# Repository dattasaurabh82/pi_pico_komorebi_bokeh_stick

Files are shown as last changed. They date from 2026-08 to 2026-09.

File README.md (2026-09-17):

# Komorebi (木漏れ日) Bokeh (暈け / ボケ) Stick

An ambient light installation: a Raspberry Pi Pico 2 W with a Pico DVI Sock
feeds a small pico projector, casting slowly breathing komorebi-like light
dapples (sunlight through foliage) onto a wall. Everything is generated
procedurally on the microcontroller: no video files, no computer. With
WiFi it quietly learns what the sky outside is doing and, by default,
gives back what the day withholds (see "A lamp that answers the sky").

Best viewed with the projector slightly defocused: the optical blur turns the
rendered falloffs into true soft penumbra.

## Hardware

- Raspberry Pi Pico 2 W (RP2350 + CYW43439 WiFi). A plain Pico / Pico W
  (RP2040) also runs the renderer; WiFi needs a W board.
- Pico DVI Sock, Luke Wren's CC0 design (the pi3g/buyzero production run;
  the Adafruit DVI Sock is the same pin map): D0 GP12/13, CK GP14/15,
  D2 GP16/17, D1 GP18/19.
- Any HDMI display or projector (signal is DVI 640x480@60, content 320x240)
- One momentary button (GP7 to GND) and a KY-040 rotary encoder
  (GP6/8/9), see below.

### Wiring

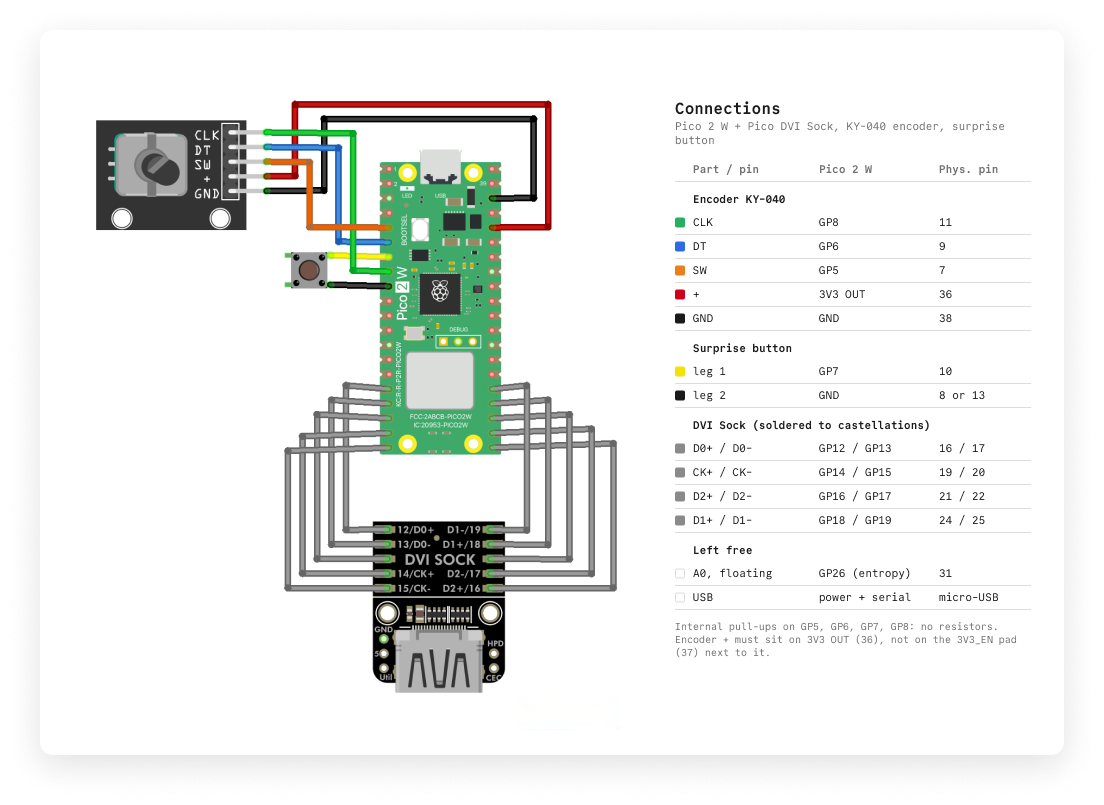
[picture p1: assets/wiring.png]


### Enclosure

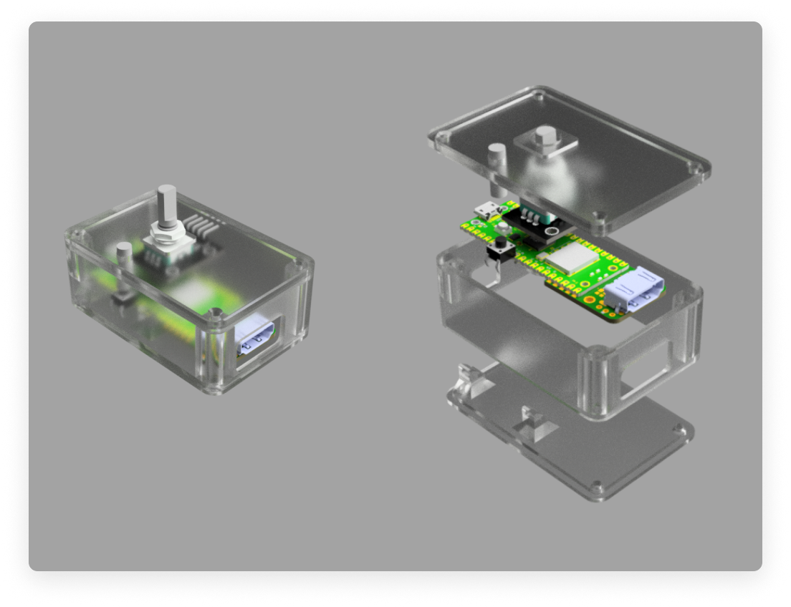
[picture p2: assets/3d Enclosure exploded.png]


>[!Tip]
> The 3D printing enclosure items can be found here: [3D_files/draft](3D_files/draft)

---

## Firmware

### Build and flash

Requires arduino-cli with the Raspberry Pi Pico/RP2040/RP2350 (Earle
Philhower) core, NOT the Mbed core, and the "PicoDVI - Adafruit Fork"
library. Verified with core 6.0.0 and PicoDVI 1.3.2.

```bash
cd main
TMPDIR=/tmp arduino-cli compile --fqbn rp2040:rp2040:rpipico2w \
  -u -p /dev/cu.usbmodem1131201 .
```

`TMPDIR=/tmp` works around a macOS ctags bug in arduino-cli; the port
name may change between replugs (`arduino-cli board list`). The CPU speed
menu does not matter: PicoDVI sets 252 MHz itself. If serial upload hangs
or the board is wedged: hold BOOTSEL while plugging in, then

```bash
TMPDIR=/tmp arduino-cli compile --fqbn rp2040:rp2040:rpipico2w --export-binaries .
cp build/rp2040.rp2040.rpipico2w/main.ino.uf2 /Volumes/RP2350/NEW.UF2
```

Stored WiFi credentials live in the last 4 KB of flash and survive
reflashing.

## How it works

The renderer (in `main/`) is built around one constraint: the second core
is fully occupied generating the DVI signal (PicoDVI bit-bangs TMDS on
PIO, on RP2040 and RP2350 alike), and the renderer was written for a
Cortex-M0+ with no FPU. So everything expensive is precomputed once at
boot into lookup tables, and the per-frame work is integer adds,
multiplies, and shifts.

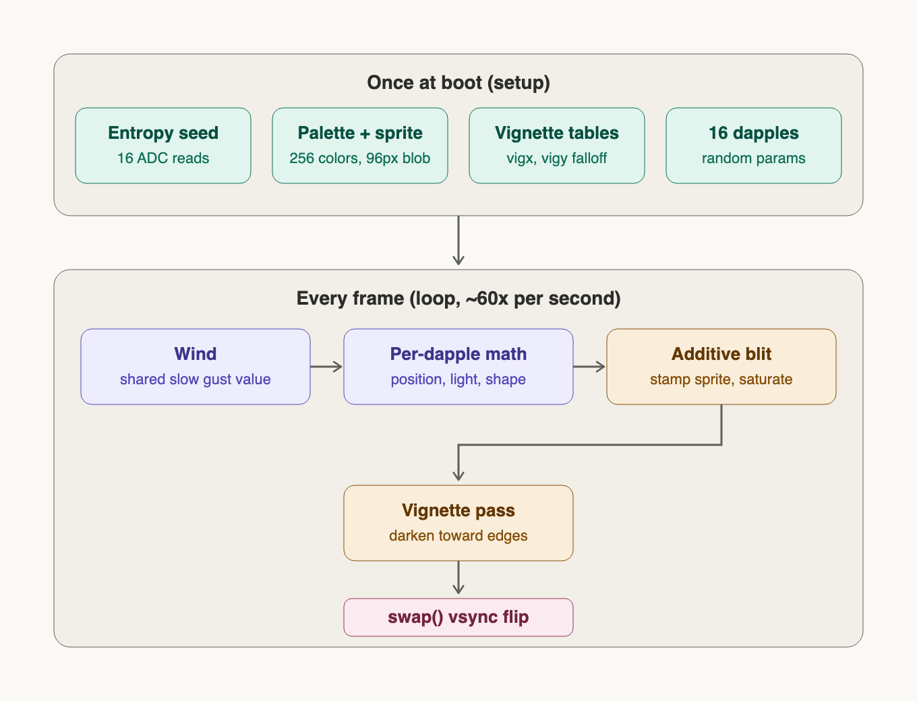
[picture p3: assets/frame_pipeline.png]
Frame pipeline


- **8-bit paletted framebuffer, double-buffered** (`DVIGFX8`, 2 x 77 KB).
  A pixel byte means "amount of light"; a 256-entry pale warm-white palette
  turns that into color. Changing the mood's color = rewriting the palette.
- **Dapples are stamps.** One 96x96 soft radial sprite (smoothstep falloff)
  is precomputed; each of the 16 dapples stamps it scaled to its own
  width/height (ellipticity) and brightness, **additively** with saturation:
  overlapping dapples merge into brighter pools, like real light.
- **Motion is sums of slow sines.** Position = anchor + two small sine
  drifts (periods 100 to 330 s, amplitudes a few px) + a shared "wind" lean.
  Brightness and shape breathe on their own slow sines. Dapples stay
  anchored and breathe; they never travel. Position is a pure function of
  time: nothing accumulates, nothing can drift off.
- **Fresh constellation every power-up.** 16 stirred floating-ADC reads seed
  the RNG; anchors, sizes, periods and phases are re-dealt each boot while
  the overall character stays fixed.
- **Vignette pass** multiplies every pixel by an edge falloff (two 1-D
  tables, `vig = vigx[x] * vigy[y]`), forcing hard black at all four raster
  edges: the wall shows floating light, not a projected rectangle.
- **`swap()`** waits for vsync and flips buffers; no tearing, no half-drawn
  frames.

## The "surprise me" button

One momentary button between **GP7 (physical pin 10) and GND (physical pin
8 or 13)**, two adjacent pins, no resistor needed (internal pull-up).
Enclosure label: *surprise me*.

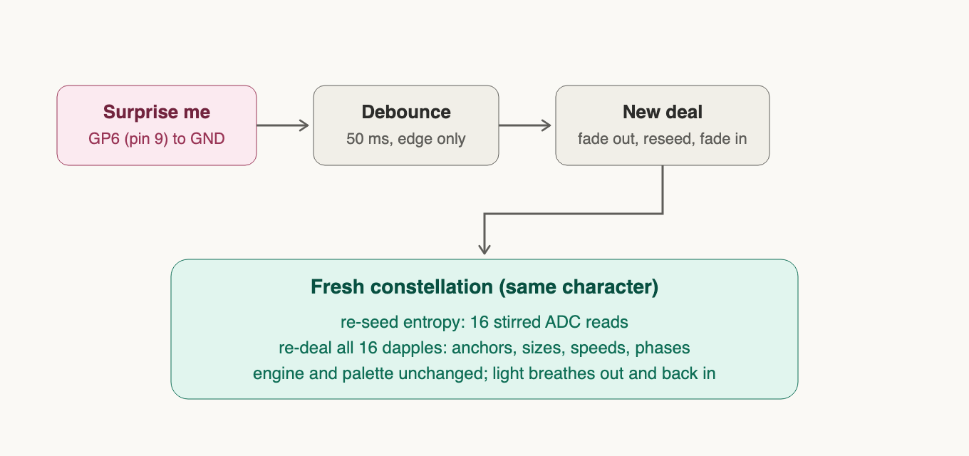
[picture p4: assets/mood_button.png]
Surprise button flow


A press never hard-cuts. The light breathes out (~0.8 s eased fade to
black), the RNG is re-seeded from 16 stirred floating-ADC reads, all 16
dapples are re-dealt (new anchors, sizes, speeds, phases), and the light
breathes back in (~1.2 s). Same character, fresh constellation: the same
thing a power cycle does, minus the wait, plus the grace.

Debounce is 50 ms on the falling edge, and presses are ignored while a
fade is already running.

Mood *presets* (palette temperature + parameter ranges as data) remain an
easy future addition on the same engine.

## The encoder: warmth / breeze / density / contrast

A KY-040 rotary encoder (DT=GP6, CLK=GP8, SW=GP5, physical pins 9/11/7,
GND at pin 38, VCC to **3V3(OUT), never 5V, and not the 3V3_EN pad next
to it**) carries the three adjustable
parameters. Since the piece has no display, the interaction grammar is:

- **Click** cycles the selected parameter: warmth, breeze, density,
  contrast. The selected parameter *announces itself* on the wall in its
  own language. Warmth: a brief palette shimmer. Breeze: a single gust.
  Density: one dapple blinks out and back. Contrast: every pool tightens
  and brightens for a moment.
- **Turn** adjusts the selected parameter, hard-capped to safe ranges
  (warmth, breeze and contrast 0 to 100, density 8 to 28; limits chosen
  by visual spike tests, see `tests/density_spike`). Contrast is the
  "kind of light" dial: at 0 the pools are big, soft and dim like an
  overcast day, at 100 small, bright and hard-edged like full sun.
- After 30 s without interaction, selection falls back to warmth (the
  most lamp-like expectation).
- **Long-press** (0.6 s) forgets the stored WiFi network and reboots into
  the setup portal (next section).

Density changes never re-deal the field: all 28 dapples always exist and
melt in/out of visibility, so turning the knob feels continuous.

The four dials set the baseline. When the piece is online, the sky adds
its own offset on top (next section); the serial log shows both numbers
per detent, "set" and "on the wall".

The encoder is read via **pin-change interrupts** (full quadrature
table), not polling: the render loop runs at 60 Hz (vsync-locked), far
too slow to poll a fast twirl. The four parameters are session-only by design; see the flash rule below.

## WiFi: boot-time setup portal

WiFi exists so the piece can later react to time of day and weather
(not implemented yet). Connecting is solved first, and it is deliberately
plain: no third-party WiFi manager, only the WiFi, WebServer, DNSServer
and EEPROM libraries that ship with the core (`main/wifi_portal.*`,
about 200 lines).

Every boot, before the projector image starts:

1. Read the stored network from EEPROM and try to join it (15 s).
2. Joined: the light starts, online.
3. Not joined, or nothing stored: the board becomes an access point named
   **komorebi** (WPA2 password `komorebi`, both in `config.h`). Join it
   with a phone or laptop; the captive page opens by itself (or open
   http://192.168.4.1). Pick your network from the scanned list, type its
   password (there is a show-password toggle), Save. The board stores it
   and reboots into step 1. A Rescan button drops the AP for a few seconds
   to scan again; rejoin and reload.
4. Nobody configures anything within 3 minutes: the AP goes away and the
   light starts offline. Next power cycle tries again.

To move the piece to another network, long-press the encoder: the board
reboots into step 3. If a Mac is attached, the boot log is on the USB
serial port at 115200 (`[wifi]` lines; the board waits 2 s for a host).

**The flash rule** (why all of this happens before the video starts) is
explained under "Two hard-won facts" below.

## A lamp that answers the sky (in progress)

Once the piece is online it learns, roughly, what the sky is doing
outside: where the sun is, how cloudy or rainy it is, how windy, what
season. It
then uses that knowledge the way a good lamp would, not the way a window
would. On a grey November afternoon it grows brighter, warmer and denser,
like a summer canopy that isn't there. At night it becomes the light the
day withheld. On a sunny June noon it mostly leaves you alone, because
nothing needs compensating. We call this **complement** mode, and it is
the default.

The other mode, **mirror**, does the opposite: the wall shows the sky as
it is. Night is dim and cool, a storm is lively, winter is sparse. Same
model, sign flipped.

Switching between the two is part of the "surprise me" gesture: press
once and the light breathes out and back in with a fresh constellation,
as always. Press twice quickly and it breathes back in as the other
world. The breath is the announcement; there is no other indicator.

What the data changes is deliberately small and slow. Your encoder
settings for warmth, breeze, density and contrast are the intent; the
sky only nudges around them, and every nudge fades in over minutes, so
an hourly update never pops. One constant sets how much the sky is
allowed to nudge at all. Five things are nudged: warmth (sun height,
cooled by cloud), breeze (wind), density (season), brightness (sun and
cloud), contrast (cloud and rain: overcast light is flat, sun is crisp).

Where the knowledge comes from, all free, no accounts, no keys:

- **Open-Meteo** for cloud cover, wind, precipitation, sunrise and sunset,
  and the local time offset. One small request at every boot and sigh.
- **NTP** (the same time servers every computer uses) for the clock.
- **ip-api.com** for a city-level location from the network the piece is
  on, so it still knows where it is after moving house. The sun's height
  and direction are then computed on the board itself, no service needed.

And when it doesn't know? It behaves exactly as it does today. No WiFi,
no data: neutral, both modes identical, the surprise button still works.
Weather fetch failed: the last values are kept for a few hours, then the
piece slowly returns to neutral. Nothing about the sky is ever written
to flash (see the flash rule), so a cold offline boot is simply the
piece you already have.

Status: live on the wall since 14 Sept 2026, in tuning. `SKY_INFLUENCE`
in config.h sets how much the sky may push (1.0 while tuning, 0.3 is
the intended "you'd notice side by side" level). To see it work with a
serial console, follow the step-by-step script in
[tests/README.md](tests/README.md#manual-test-script-for-the-wall-build-main).

## Two hard-won facts about WiFi and video on one Pico

If you build something like this, these two cost us the most time. Both
are handled in the code, and both are worth knowing before you change it.

**1. Flash writes and video do not mix.** Writing the Pico's flash while
the DVI output runs freezes the whole board, even with the video core
stopped first (`tests/eeprom_dvi_spike`, `tests/core1reset_flash_spike`).
So the WiFi portal, and every EEPROM write, runs strictly before
`display.begin()`, and "reconfigure later" is a flag in a watchdog
scratch register plus a reboot, never a live write.

**2. WiFi traffic and video do not mix either.** With DVI live, any
network traffic degrades the station link within minutes (the board
stays "connected" but can't be reached) and, worse, within hours the
video core stops producing frames: the wall goes black and the board
needs a power cycle. Ruled out by experiment: the 252 MHz clock (perfect
without video), power saving, the render code. Left standing: DVI's DMA
and PIO activity against the WiFi chip's SPI DMA. With the radio switched
off after the boot fetch the board ran 16.5 hours without a single
dropped frame; with traffic it died four times in two days.

So the piece does all its networking in the few seconds before the video
starts, and refreshes the sky with a **sigh**: every three hours the
light breathes out, the board reboots with your dials and mode preserved
in watchdog scratch registers, joins WiFi, fetches, and breathes back in.
About ten seconds of dark, three times a day. Sun position and season
stay live from the clock in between; only the weather ages, and it is
kept for six hours before fading toward neutral.

The reboot also resets the video output, so a monitor that lost sync
during the dark gap re-syncs by itself (tested).

How this was found: `tests/sky_spike` with a `SPIKE_MODE` switch (no
video / no video at 252 MHz / video live), a Mac-side log pinging the
router and the weather API in parallel, a hardware watchdog with a
"last stage" recorder in a scratch register, an overnight bisect with the
radio off, and `tests/flash.sh` for reliable flashing on macOS. The
live-traffic code path (keepalive, hourly fetch, reconnects) is still in
`sky.cpp` behind `SKY_LIVE_NET`, off.

## Code layout (main/)

```
main.ino        thin orchestrator: wifi.boot() → display → inputs → engine → swap
config.h        every pin, limit, tuning constant, WiFi name/timeouts
engine.*        KomorebiEngine: dapples, palette, fades, announcements
render.*        fx:: sprite/vignette tables, additive scaled blit
controls.*      RotaryEncoder (ISR quadrature) + ClickButton grammar
params.h        the three user values + capped adjustment
wifi_portal.*   boot-time connect / captive portal / forget-and-reboot
sky_core.*      pure sky maths: JSON scan, sun position, model, decay (host-tested)
sky.*           SkyClient: fetches, clock, keepalive, reconnects, staleness
```

## Repo layout

```
main/            current installation sketch (build this)
komorebi/        variant A, first anchored-dapple baseline (frozen)
komorebi_noise/  variant C, morphing noise-field style (frozen reference)
tests/           proven experiments, setup notes, troubleshooting, fallback plans
assets/          diagrams (SVG sources + rendered PNGs)
```

Variant history and comparisons: see commit log. A/C are kept diffable
against `main/` on purpose.

---

## LICENSE

[MIT](LICENSE)

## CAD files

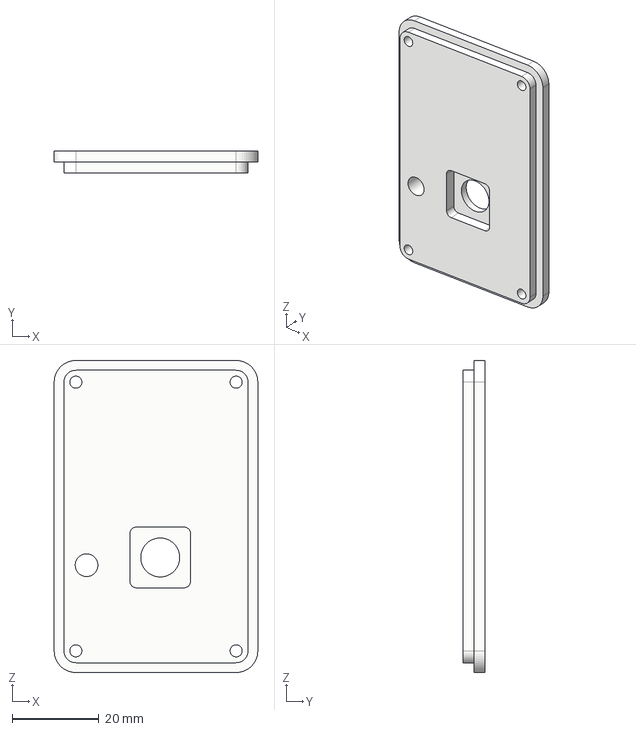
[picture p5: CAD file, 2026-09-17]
3D_files/draft/CAP.step
47.0 x 5.00 x 72.0 mm

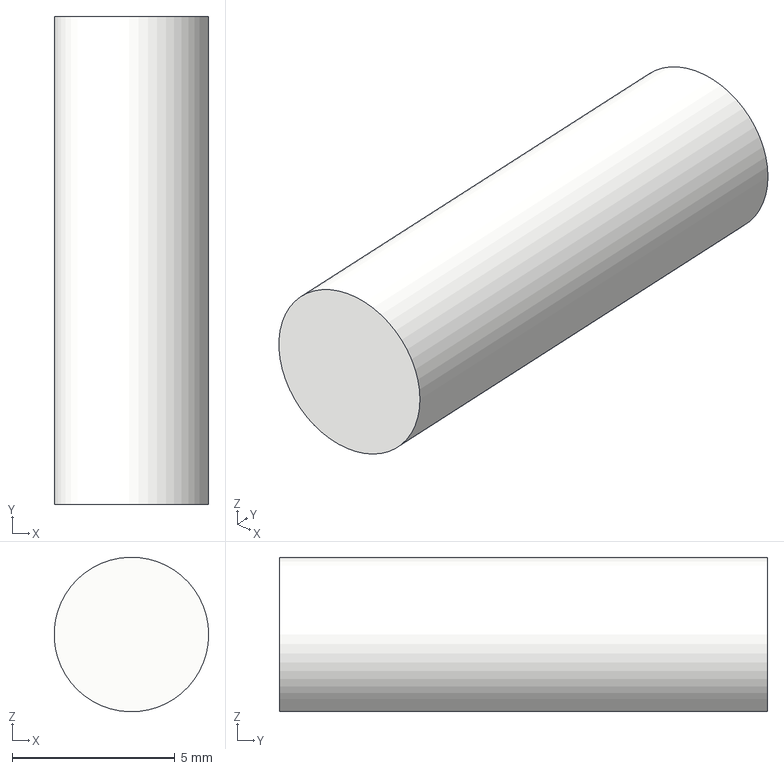
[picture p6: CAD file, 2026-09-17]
3D_files/draft/BTN_EXTENDER.step
4.75 x 15.0 x 4.75 mm

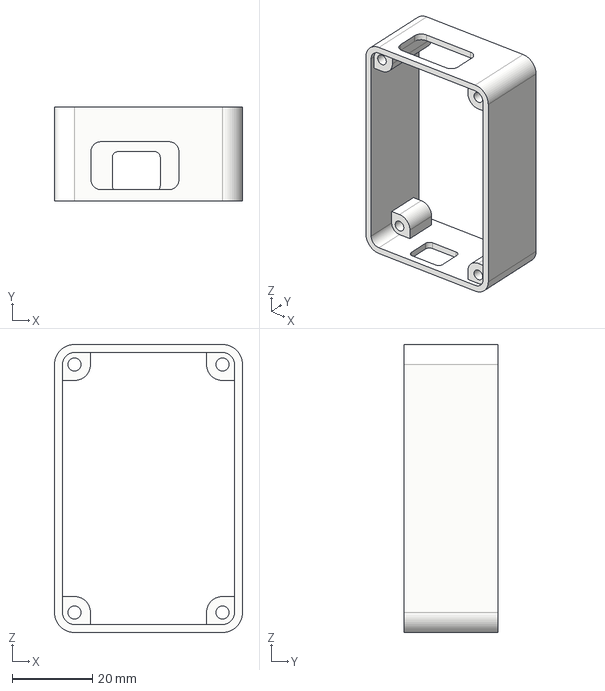
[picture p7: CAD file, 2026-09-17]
3D_files/draft/WALL.step
47.0 x 23.5 x 72.0 mm

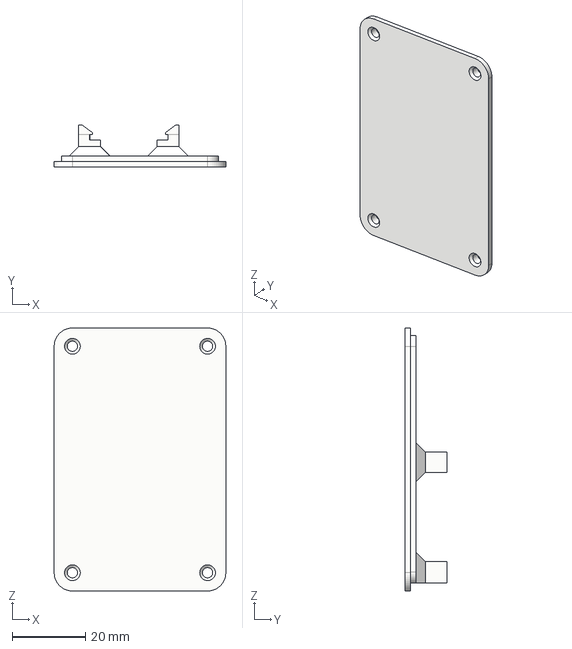
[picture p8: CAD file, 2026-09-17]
3D_files/draft/BASE.step
47.0 x 11.4 x 72.0 mm

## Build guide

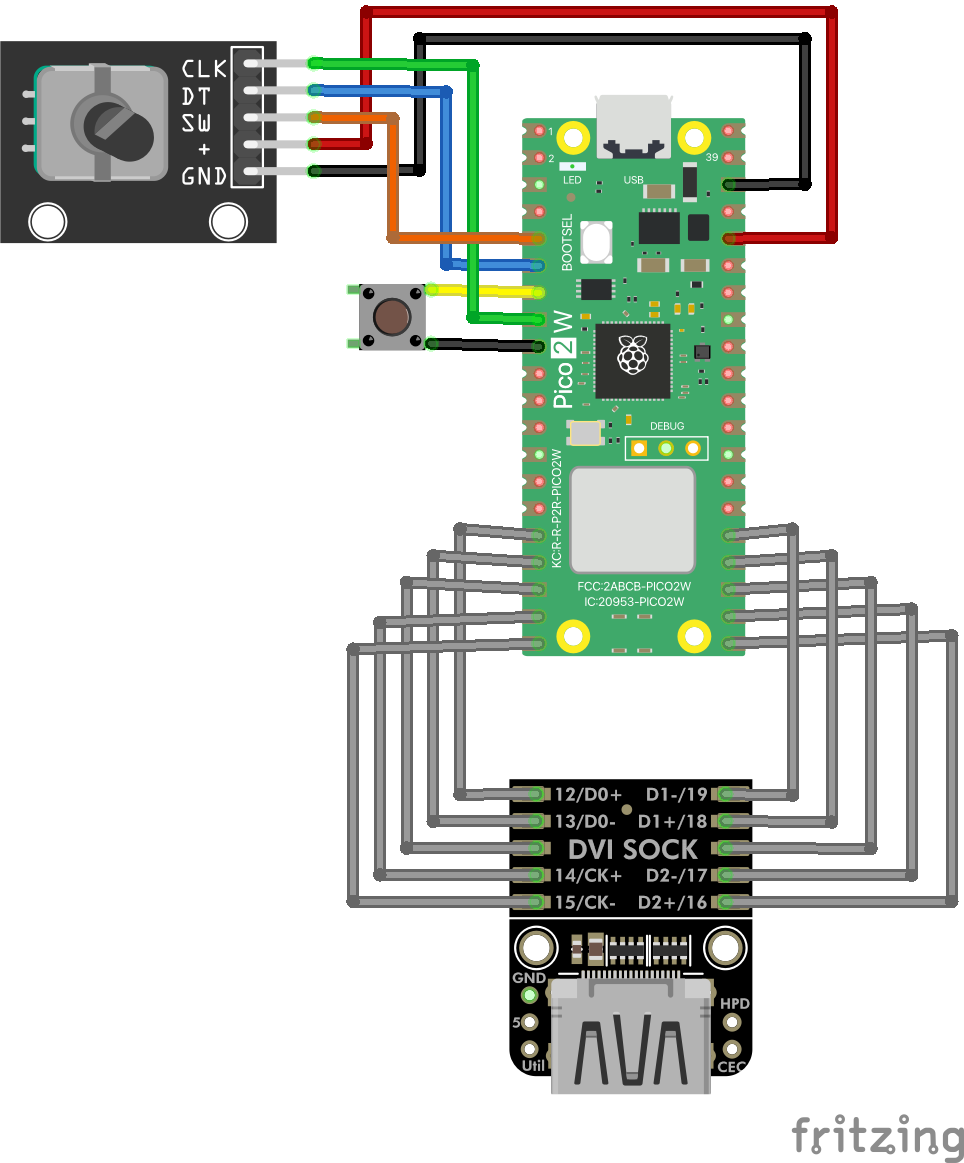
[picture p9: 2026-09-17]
assets/wiring_bb.png

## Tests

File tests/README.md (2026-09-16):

# pi_pico_komorebi: DVI and WiFi setup notes

Hardware: Raspberry Pi Pico 2 W (RP2350; a plain Pico RP2040 also works for
video) + Pico DVI Sock (Luke Wren design, pi3g/buyzero or Adafruit), HDMI out.
Toolchain: Arduino IDE / arduino-cli with the **Raspberry Pi Pico/RP2040/RP2350
(Earle Philhower) core**, the Mbed RP2040 core does NOT work with PicoDVI.
Library: PicoDVI - Adafruit Fork (1.3.2), which on RP2350 still bit-bangs
TMDS on PIO with core1 (no HSTX).

## The one code change that made video work

The `16bit_hello` example ships configured for the **Adafruit Feather RP2040
DVI**, which routes TMDS on different GPIOs. On a plain Pico with the DVI
Sock, that line must use the Sock's pin map:

```cpp
// before (example default): video goes to pins the Sock isn't on, black screen
DVIGFX16 display(DVI_RES_320x240p60, adafruit_feather_dvi_cfg);

// after: matches the DVI Sock (D0 GP12/13, CK GP14/15, D2 GP16/17, D1 GP18/19)
DVIGFX16 display(DVI_RES_320x240p60, pico_sock_cfg);
```

## Board / build settings

- Board: Raspberry Pi Pico 2 W, `rp2040:rp2040:rpipico2w` (plain Pico:
  `rp2040:rp2040:rpipico`)
- CPU speed menu: irrelevant. DVI 640x480 needs a 252 MHz TMDS bit clock and
  the library sets it inside `display.begin()` via `set_sys_clock_khz()`.
- Upload method: default (UF2). BOOTSEL volume is named `RPI-RP2` on RP2040
  and `RP2350` on RP2350.

## Spikes in this folder

- `hello_world` the first working video, DVIGFX16
- `dvigfx8_test` paletted double-buffered canvas, chosen for the piece
- `density_spike` how many dapples before additive blowout (8 to 28)
- `eeprom_dvi_spike` EEPROM.commit() with DVI live on RP2040: video core dies
- `wifi_dvi_spike` (Pico 2 W) scan + softAP + WebServer with DVI live at
  252 MHz sysclk: PASS, the fixed CYW43 PIO clock divider is fine
- `core1reset_flash_spike` (Pico 2 W) EEPROM.commit() with DVI live after
  stopping core1 (v1 `multicore_reset_core1`, v2 PSM hold): the whole board
  freezes inside the commit, USB dead. Recovery: BOOTSEL replug. This is why
  every flash write in `main/` happens before `display.begin()`.
- `sky_host` host-side tests for `main/sky_core` (`./run.sh`, clang, no
  hardware): 54 checks against real Open-Meteo / ip-api responses, broken
  inputs, sun position vs sunrise/sunset and solstices.
- `sky_spike` (Pico 2 W) the real `main/sky.*` via symlinks, DVI live,
  frame-stall meter, serial commands for failure injection, `SPIKE_MODE`
  switch (0 no DVI, 1 no DVI at 252 MHz, 2 DVI live). Found that DVI
  activity degrades the STA link and that a 15 s UDP keepalive holds it.
  See the main README, "Two hard-won facts".
- `flash.sh <sketch_dir>` compile + 1200-baud reset + wait for the RP2350
  volume + copy. Use this; arduino-cli's own upload scan gives up before
  the volume mounts on macOS.

## Failure signals

- Solid video: all good.
- Onboard LED blinking ~1 Hz: `display.begin()` failed (RAM / config).
- Dead LED + black screen: wiring / solder joints on Sock pins GP12 to GP19.
- Dark screen for up to 3 min after boot with a "komorebi" WiFi network
  visible: the setup portal is waiting (see main README).
- USB port present but every open blocks: board frozen by a flash write
  with DVI live. BOOTSEL replug.

## macOS quirks

- **arduino-cli builds fail with "exit status 1"** and a buried `ctags: cannot
  open temporary file`: the bundled ctags 5.8 chokes on macOS's per-user
  TMPDIR. Fix: prefix builds with `TMPDIR=/tmp`:

  ```bash
  TMPDIR=/tmp arduino-cli compile --fqbn rp2040:rp2040:rpipico2w --export-binaries hello_world
  ```

- **Serial upload is flaky**: the 1200-baud touch that reboots the Pico into
  BOOTSEL doesn't always enumerate cleanly on macOS. If it hangs at "Waiting
  for upload port", hold BOOTSEL while plugging in and copy the built UF2 onto
  the `RP2350` (or `RPI-RP2`) volume as `NEW.UF2`.
- **Reading the boot log**: `cat /dev/cu.usbmodem*` can block forever on a
  wedged board. A non-blocking open/read loop (python `os.open` with
  `O_NONBLOCK`) is safer; the main sketch waits 2 s for a host so the first
  lines are not lost.

## Manual test script for the wall build (main/)

Open the serial port at 115200 (the board waits 2 s for a host at boot),
`LOG_VERBOSE 1` in config.h. Each step: what to do, what the wall does,
what the log says.

1. **Boot with the Mac attached.** Replug the board. Within ~3 s: the
   `[wifi] connected` line, three fetch lines (location, ntp, weather),
   the `[sky] ---- snapshot ----` block (time, place, sun, weather, model,
   mode, targets), then `[sky] targets (boot): ...`. Over the next 3 min
   the light slides from the encoder baseline to the sky targets; the
   `[sky] applied: ... -> wall ...` line every minute shows the creep.
2. **Surprise, single click.** Wall: breathe out, new constellation,
   breathe in. Log: `[btn] surprise: breathe out, re-deal, breathe in`.
   A click during the fade logs `ignored (fade running)`.
3. **Double-click** (second press within 350 ms). The first press still
   breathes. Log: `[btn] double-click: mode -> mirror` and a fresh snapshot
   whose targets have flipped sign (warmth +10 becomes -10, contrast +14
   becomes -14, etc.). The
   wall does not jump: the offsets slide over 3 min, so only the direction
   of drift changes. Double-click again flips back to complement.
4. **Encoder click.** Log: `[enc] click: selected breeze (announcing)`,
   wall: one gust. Density: one pool blinks. Warmth: a palette shimmer.
   Contrast: all pools tighten and brighten for a moment. Four clicks
   bring you back to warmth.
5. **Encoder turn.** Per detent: `[enc] turn +1: warmth set 54 (on the
   wall 64 incl. sky)`. "set" is the encoder value, "on the wall" adds the
   sky offset: what the palette is actually built from.
6. **Idle 30 s** with breeze or density selected: `[enc] idle 30 s:
   selection back to warmth`.
7. **Long-press the encoder** (0.6 s): `[enc] long-press: forget WiFi,
   reboot into portal`, then the portal as in the README.
8. **The sigh.** After `SKY_SIGH_MINUTES` (set it to 3 for a test):
   `[sigh] N min up: breathing out, will reboot to refresh the sky`, the
   port drops for a second, then `[boot] sigh reboot: dials restored
   (...)`, the three fetch lines, a snapshot, `radio off`. Dials, mode
   and the picture must all be back.
9. **Watchdog.** If the loop ever stalls 8 s the board reboots itself and
   the boot line says `WATCHDOG REBOOT ... last stage N` (stages listed in
   `log.h`). Seeing this line is a bug report; save the log.

Knobs while testing (config.h): `SKY_INFLUENCE` (1.0 = full swing for
tuning, 0.3 = subtle), `SKY_RANGE_*` per parameter, `SKY_SLEW_S` (180;
set 20 to watch the slide), `LOG_VERBOSE` (0 = boot, fetches, mode
flips, long-press, errors only). The look of "flat" vs "crisp" lives in
`engine.cpp` (`sizeM`, `briM`, the palette gamma multiplier).

Reading the model line: `light warmth motion foliage crisp`, each 0..1
with 0.5 = an average day. Complement pushes every offset away from the
value, mirror toward it; a 0.5 gives a zero offset in both modes.

## The "sigh": implemented (16 Sept 2026)

Status: this is the shipped design, not a fallback. The keepalive approach
was tried and lost the bisect (see the main README, "Two hard-won facts").
Interval `SKY_SIGH_MINUTES` in config.h (180). Tested 4 of 4 cycles at a
3-minute interval with the user watching: dials and mode restored, fresh
fetch each time, monitor re-synced after every dark gap.

### The problem it sidesteps

Two things this board cannot do reliably while the DVI output is running:
write flash, and keep a WiFi station link healthy over hours. Both work
fine before `display.begin()`. So instead of fighting for a live link,
the piece can do all its networking in the few seconds before the video
starts, and simply start over once an hour.

### What it looks like on the wall

Every three hours (interval in `config.h`), the light breathes out over
about a second, the wall is dark for about ten seconds (boot, WiFi join,
three fetches), and the light breathes back in with a fresh constellation. The same gesture as the
"surprise me" button, on a slow clock. On a piece that changes over
minutes, one absence per hour is part of the character, not a glitch.

### What happens underneath

1. The engine fades to black (the existing surprise fade-out).
2. Warmth, breeze, density, contrast and the complement/mirror mode are
   written to watchdog scratch registers 1 and 2. These survive
   `rp2040.reboot()` and touch no flash. Register 0 is the portal flag,
   register 3 the stage recorder.
3. `rp2040.reboot()`.
4. Boot as today: WiFi joins the stored network, the sky layer fetches
   location, clock and weather (about 1.5 s, all before the video),
   the scratch registers restore the parameters, the video starts, the
   light fades in.

Nothing about the sky needs to persist: the model is rebuilt from the
boot fetch. If WiFi is down at that boot, the piece runs neutral until
the next sigh, exactly like an offline boot today.

### What it costs

- 3 to 5 seconds of darkness per interval.
- A new constellation each time (could be kept by also saving the RNG
  seed to a scratch register, if continuity matters more than freshness).
- Nothing else: no keepalive, no reconnect logic, no live fetch code path
  needs to be exercised at all.

### Why it is the default

Live traffic under video killed the video core four times in two days;
the radio-off run went 16.5 hours without a dropped frame. Ten seconds of
dark three times a day is the price of a board that never needs a plug
pulled.

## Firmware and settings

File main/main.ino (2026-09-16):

// pi_pico_komorebi — main.ino: thin orchestrator only.
// All tuning lives in config.h; behavior in engine/render/controls/params.
//
// Hardware: Pico 2 W + Pico DVI Sock (pico_sock_cfg, GP12-19).
//   GP7 (pin 10): "surprise me" button, to GND (pin 8 or 13).
//   GP6/8/5 (pins 9/11/7): KY-040 encoder DT/CLK/SW, GND at pin 38, VCC 3V3.
// WiFi: on boot, join the stored network or open the "komorebi" AP portal
//   (wifi_portal.h). Everything WiFi that writes flash happens BEFORE
//   display.begin(): a flash write with DVI live freezes the board.
// Interaction: encoder click cycles warmth -> breeze -> density -> contrast (the
// selected parameter announces itself visually); turning adjusts it.
// Selection falls back to warmth after SELECT_TIMEOUT_MS of inactivity.
// Encoder long-press: forget the WiFi network, reboot into the portal.

#include <PicoDVI.h>
#include "config.h"
#include "params.h"
#include "controls.h"
#include "engine.h"
#include "wifi_portal.h"
#include "sky.h"
#include "log.h"

// Subclass only to read the video core's late-scanline counter (protected).
struct DVIGFX8Probe : public DVIGFX8 {
  using DVIGFX8::DVIGFX8;
  unsigned lateScanlines() const { return dvi0.late_scanline_ctr; }
};
DVIGFX8Probe display(DVI_RES_320x240p60, true, pico_sock_cfg);

KomorebiEngine engine;
RotaryEncoder  encoder;
ClickButton    encoderBtn;
ClickButton    surpriseBtn;
Params         params;
WifiPortal     wifi;
SkyClient      skyc;       // sky data layer
bool           skyComplement = SKY_DEFAULT_COMPLEMENT;   // false = mirror
uint32_t       lastSurpriseClick = 0;

Param    selected = Param::Warmth;
uint32_t lastInteraction = 0;

// Dials and mode survive a sigh reboot in watchdog scratch registers
// ([0] portal flag, [3] stage recorder; [1] dials, [2] magic + mode).
static constexpr uint32_t SIGH_MAGIC = 0x53494700;   // "SIG" + mode bit
static void saveStateForReboot() {
  watchdog_hw->scratch[1] = ((uint32_t)params.warmth << 24) | ((uint32_t)params.breeze << 16) |
                            ((uint32_t)params.density << 8) | (uint32_t)params.contrast;
  watchdog_hw->scratch[2] = SIGH_MAGIC | (skyComplement ? 1 : 0);
}
static bool restoreStateAfterReboot() {
  if ((watchdog_hw->scratch[2] & 0xFFFFFF00) != SIGH_MAGIC) return false;
  uint32_t d = watchdog_hw->scratch[1];
  params.warmth = (d >> 24) & 0xFF; params.breeze = (d >> 16) & 0xFF;
  params.density = (d >> 8) & 0xFF; params.contrast = d & 0xFF;
  skyComplement = watchdog_hw->scratch[2] & 1;
  watchdog_hw->scratch[2] = 0;
  return true;
}

static const char* modeName() { return skyComplement ? "complement" : "mirror"; }
static sky::Offsets skyOffsets() {
  sky::OffsetRanges r = { SKY_RANGE_WARMTH, SKY_RANGE_BREEZE, SKY_RANGE_DENSITY, SKY_RANGE_EXPOSURE, SKY_RANGE_CONTRAST };
  return sky::mapOffsets(skyc.vector(), skyComplement ? -1 : +1, SKY_INFLUENCE, r);
}
static void pushSky(const char* why) {        // recompute targets, hand to engine, say so
  STAGE(11);
  sky::Offsets o = skyOffsets();
  engine.setSkyTargets(o);
  LOGV("[sky] targets (%s): warmth %+.0f breeze %+.0f density %+.1f exposure %+.0f%% contrast %+.0f\n",
       why, o.warmth, o.breeze, o.density, o.exposure * 100.0f, o.contrast);
}

void setup() {
  SkyClient::prepareRadioForDvi();  // first: WiFi SPI divisor for the 252 MHz DVI clock
  bool wdReboot = watchdog_caused_reboot();
  uint32_t lastStage = watchdog_hw->scratch[3];
  STAGE(0);
  wifi.boot(); // connect, or portal, or time out. MUST precede display.begin().
  bool sighReboot = restoreStateAfterReboot();
  if (sighReboot)   LOGE("[boot] sigh reboot: dials restored (warmth %d breeze %d density %d contrast %d, %s)\n",
                         params.warmth, params.breeze, params.density, params.contrast, modeName());
  else if (wdReboot) LOGE("[boot] WATCHDOG REBOOT: the loop stalled >8 s, last stage %lu (see log.h)\n", (unsigned long)lastStage);
  else               LOGE("[boot] power-on / normal reset\n");
  if (wifi.connected()) {
    skyc.setCredentials(wifi.ssid(), wifi.pass());
    skyc.bootSync(10000);            // location, clock, weather. Still pre-DVI.
  }
  STAGE(10); skyc.dumpSnapshot(Serial, modeName(), skyOffsets());
  STAGE(11); pushSky("boot");        // engine slides from baseline to these over SKY_SLEW_S
  if (sighReboot) engine.snapSkyToTargets();   // it was dark anyway: no 3-min drift after a sigh
  STAGE(0);
#if !SKY_LIVE_NET
  if (wifi.connected()) { WiFi.disconnect(); WiFi.mode(WIFI_OFF); LOGE("[sky] radio off (SKY_LIVE_NET 0): boot data only\n"); }
#endif
  if (!display.begin()) { // RAM alloc failed -> blink LED forever
    pinMode(LED_BUILTIN, OUTPUT);
    for (;;) digitalWrite(LED_BUILTIN, (millis() / 500) & 1);
  }
  engine.begin(&display);
  display.swap(false, true); // palette into both buffers
  rp2040.wdt_begin(8000);    // from here on: a loop stall > 8 s reboots the board
  surpriseBtn.begin(PIN_BTN_SURPRISE);
  encoderBtn.begin(PIN_ENC_SW);
  encoder.begin(PIN_ENC_A, PIN_ENC_B);
}

void loop() {
  rp2040.wdt_reset();
  static uint32_t lastMs = 0;
  uint32_t now = millis();
  float dt = (now - lastMs) / 1000.0f;
  if (dt > 0.1f) dt = 0.1f; // first frame / hiccups
  lastMs = now;
  float t = now / 1000.0f;

  // --- inputs ---
  STAGE(13);
  if (surpriseBtn.poll(now) == ClickButton::CLICK) {
    if (now - lastSurpriseClick < DOUBLE_CLICK_MS) {   // 2nd click: flip the world
      skyComplement = !skyComplement;
      LOGE("[btn] double-click: mode -> %s\n", modeName());
      pushSky("mode flip");
      STAGE(10); skyc.dumpSnapshot(Serial, modeName(), skyOffsets()); STAGE(0);
    } else if (!engine.surpriseBusy()) {
      LOGV("[btn] surprise: breathe out, re-deal, breathe in\n");
      engine.startSurprise();
    } else {
      LOGV("[btn] surprise click ignored (fade running)\n");
    }
    lastSurpriseClick = now;
    lastInteraction = now;
  }

  static const char* PNAME[4] = { "warmth", "breeze", "density", "contrast" };
  ClickButton::Event ev = encoderBtn.poll(now);
  if (ev == ClickButton::CLICK) {
    selected = (Param)(((uint8_t)selected + 1) % PARAM_COUNT);
    engine.announce(selected, t);   // the param shows itself on the wall
    LOGV("[enc] click: selected %s (announcing)\n", PNAME[(uint8_t)selected]);
    lastInteraction = now;
  } else if (ev == ClickButton::LONG_PRESS) {
    LOGE("[enc] long-press: forget WiFi, reboot into portal\n");
    wifi.requestPortalAndReboot();  // forget network, come back in the portal
  }

  int det = encoder.consumeDetents();
  if (det != 0) {
    params.adjust(selected, det);
    int v = selected == Param::Warmth ? params.warmth : selected == Param::Breeze ? params.breeze : selected == Param::Density ? params.density : params.contrast;
    int e = selected == Param::Warmth ? engine.effWarmth() : selected == Param::Breeze ? engine.effBreeze() : selected == Param::Density ? engine.effDensity() : engine.effContrast();
    LOGV("[enc] turn %+d: %s set %d (on the wall %d incl. sky)\n", det, PNAME[(uint8_t)selected], v, e);
    lastInteraction = now;
  }

  // Idle fallback: after a while, turning means warmth again (the most
  // lamp-like expectation for someone approaching the object cold).
  if (selected != Param::Warmth && (now - lastInteraction) > SELECT_TIMEOUT_MS) {
    selected = Param::Warmth;
    LOGV("[enc] idle %lu s: selection back to warmth\n", SELECT_TIMEOUT_MS / 1000);
  }

  // --- frame ---
  STAGE(12);
  engine.renderFrame(t, dt, params);
  STAGE(14);
  display.swap();
  STAGE(0);

  // --- sky: hourly refresh, reconnects; targets re-pushed every minute
  //     (the sun moves) and right after a successful fetch ---
  uint32_t fetchesBefore = skyc.fetchCount();
#if SKY_LIVE_NET
  skyc.tick();
#endif
  static uint32_t lastSkyPush = 0;
  if (skyc.fetchCount() != fetchesBefore) {
    pushSky("fetch");
    STAGE(10); skyc.dumpSnapshot(Serial, modeName(), skyOffsets()); STAGE(0);
    lastSkyPush = now;
  } else if (now - lastSkyPush > 60000) {
    lastSkyPush = now;
    pushSky("minute");
    const sky::Offsets& a = engine.skyApplied();
    LOGV("[sky] applied: warmth %+.1f breeze %+.1f density %+.1f exposure %+.0f%% contrast %+.1f -> wall warmth %d breeze %d density %d contrast %d | dvi late %u\n",
         a.warmth, a.breeze, a.density, a.exposure * 100.0f, a.contrast, engine.effWarmth(), engine.effBreeze(), engine.effDensity(), engine.effContrast(),
         display.lateScanlines());
  }
  static uint32_t lastSkyLog = 0;
  if (now - lastSkyLog > 600000) { lastSkyLog = now; skyc.logStatus(Serial); }

  // --- the sigh: breathe out, reboot with dials kept, fetch fresh sky pre-DVI ---
  if (SKY_SIGH_MINUTES && now > SKY_SIGH_MINUTES * 60000UL && !engine.surpriseBusy() && !engine.sighDone()) {
    LOGE("[sigh] %lu min up: breathing out, will reboot to refresh the sky\n", now / 60000UL);
    engine.startSigh();
  }
  if (engine.sighDone()) {
    saveStateForReboot();
    Serial.flush();
    delay(100);
    rp2040.reboot();
  }
}

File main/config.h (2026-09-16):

// config.h — every pin, limit, and tuning constant in one place.
// If you're adjusting the feel of the piece, this is the only file to touch.
#pragma once
#include <stdint.h>

// ---------- Display geometry ----------
constexpr int SCREEN_W = 320;
constexpr int SCREEN_H = 240;

// ---------- Pins (physical pin in parentheses) ----------
constexpr uint8_t PIN_BTN_SURPRISE = 7; // (10) momentary to GND, pull-up
constexpr uint8_t PIN_ENC_A        = 6; // (9)  KY-040 DT  — 3V3 module!
constexpr uint8_t PIN_ENC_B        = 8; // (11) KY-040 CLK
// NOTE: A/B vs CLK/DT assignment is arbitrary for the quadrature decoder —
// swapping them only inverts the rotation direction. If clockwise turns
// the values DOWN after wiring, negate the detents in main.ino
// (params.adjust(selected, -det)) instead of resoldering.
constexpr uint8_t PIN_ENC_SW       = 5; // (7)  encoder push, to GND (was GP9 on the RP2040 build)
// A0 (GP26) stays free-floating: entropy source. DVI Sock owns GP12-19.

// ---------- WiFi (boot-time portal, see wifi_portal.h) ----------
constexpr const char* WIFI_AP_SSID = "komorebi";
constexpr const char* WIFI_AP_PASS = "komorebi";  // WPA2, min 8 chars
constexpr uint32_t WIFI_CONNECT_TIMEOUT_MS = 15000;  // stored network
constexpr uint32_t WIFI_PORTAL_TIMEOUT_MS  = 180000; // then start offline

// ---------- Sky-driven light (see README "A lamp that answers the sky") ----------
// The sky pushes each parameter away from (complement) or toward (mirror)
// the encoder setting. Full swing per parameter when the sky is extreme:
constexpr float SKY_RANGE_WARMTH   = 25.0f;  // points on 0..100
constexpr float SKY_RANGE_BREEZE   = 25.0f;  // points on 0..100
constexpr float SKY_RANGE_DENSITY  = 5.0f;   // dapples
constexpr float SKY_RANGE_CONTRAST = 25.0f;  // points on 0..100 (from cloud/rain: crispness)
constexpr float SKY_RANGE_EXPOSURE = 0.30f;  // palette gain, +-30% mid-tones
constexpr float SKY_INFLUENCE      = 1.0f;   // 0 = off, 1 = full swing. Tuning: start visible.
constexpr float SKY_SLEW_S         = 180.0f; // seconds to travel a full swing (never pops)
constexpr uint32_t DOUBLE_CLICK_MS = 350;    // surprise button: 2nd click flips complement/mirror
constexpr bool     SKY_DEFAULT_COMPLEMENT = true;

// Live network while the video runs? PROVEN 15/16 Sept 2026: WiFi traffic
// under DVI kills the video core within hours; radio off = 16.5 h flawless.
// Keep 0. The weather is refreshed by the "sigh" below instead.
#define SKY_LIVE_NET 0
// The sigh: every SKY_SIGH_MINUTES the light breathes out, the board reboots
// (dials and mode preserved in watchdog scratch registers), fetches fresh
// sky data before the video starts, and breathes back in. ~6 s of dark.
// 0 = never. Sun and season stay live from the clock regardless.
constexpr uint32_t SKY_SIGH_MINUTES = 180;

// ---------- Serial logging ----------
// 1: every interaction and step (clicks, detents, values, 60 s sky line).
// 0: essentials only (boot, fetches, mode flips, errors). Never per-frame.
#define LOG_VERBOSE 1

// ---------- Dapple field ----------
constexpr int N_MAX_DAPPLES = 28;   // hard ceiling (spiked: 36 saturates)
constexpr int DENSITY_MIN   = 8;    // spiked: below this feels empty
constexpr int DENSITY_MAX   = 28;
constexpr int DENSITY_DEFAULT = 16;
constexpr int SPRITE_SIZE   = 96;   // soft radial sprite, px

// ---------- User parameters (0..100 unless noted) ----------
constexpr int WARMTH_DEFAULT = 50;  // 0 = cool daylight, 100 = low amber
constexpr int BREEZE_DEFAULT = 40;  // 0 = near-still, 100 = lively
constexpr int CONTRAST_DEFAULT = 50;// 0 = overcast flat (big, soft, dim pools), 100 = crisp sun
constexpr int PARAM_STEP     = 4;   // warmth/breeze change per detent
// density moves 1 per detent (its own scale)

// ---------- Timing ----------
constexpr float FADE_OUT_S = 0.8f;  // surprise: breathe out
constexpr float FADE_IN_S  = 1.2f;  // surprise: breathe in
constexpr uint32_t DEBOUNCE_MS   = 50;
constexpr uint32_t LONGPRESS_MS  = 600;   // reserved (future: off)
constexpr uint32_t SELECT_TIMEOUT_MS = 30000; // selection falls back to warmth
constexpr float ANNOUNCE_S = 0.9f;  // param self-announcement duration
constexpr float ACT_RAMP_PER_S = 1.2f; // dapple activation fade (density)

// ---------- Vignette (frame-dissolve) ----------
constexpr int VIGNETTE_MARGIN_X = 72; // px of falloff at left/right
constexpr int VIGNETTE_MARGIN_Y = 58; // px of falloff at top/bottom

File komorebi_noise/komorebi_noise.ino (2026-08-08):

// komorebi_noise — variant C: a different style. No discrete blobs; a slowly
// evolving value-noise field pushed through a soft threshold. Light shapes
// morph / merge / split like real canopy gaps, instead of translating.

#include <PicoDVI.h>

DVIGFX8 display(DVI_RES_320x240p60, true, pico_sock_cfg);

#define W 320
#define H 240
#define CELL 16              // grid cell in px
#define GW (W / CELL + 1)    // 21 grid points
#define GH (H / CELL + 1)    // 16

static uint8_t g[GW * GH];   // current field values 0..255
static uint8_t lut[256];     // soft-threshold mapping, rebuilt each frame
// Per gridpoint temporal params: two slow sines each.
static float gf1[GW * GH], gf2[GW * GH], gp1[GW * GH], gp2[GW * GH];

static float frand(float lo, float hi) {
  return lo + (hi - lo) * (random(10000) / 10000.0f);
}

static uint32_t entropy_seed() {
  uint32_t s = micros();
  for (int i = 0; i < 16; i++) {
    s = (s << 3) ^ (s >> 5) ^ (uint32_t)analogRead(A0) ^ (s * 2654435761u);
    delayMicroseconds(37 + (s & 63));
  }
  return s;
}

void setup() {
  if (!display.begin()) {
    pinMode(LED_BUILTIN, OUTPUT);
    for (;;) digitalWrite(LED_BUILTIN, (millis() / 500) & 1);
  }
  for (int i = 0; i < 256; i++) { // pale warm-white
    float t = i / 255.0f;
    display.setColor(i, (uint8_t)(255 * powf(t, 0.75f)),
                        (uint8_t)(242 * powf(t, 0.82f)),
                        (uint8_t)(205 * powf(t, 1.05f)));
  }
  display.swap(false, true);

  randomSeed(entropy_seed());
  // Each gridpoint breathes with its own two incommensurate slow periods
  // (~45–500 s) → the field never repeats, shapes morph organically.
  for (int i = 0; i < GW * GH; i++) {
    gf1[i] = frand(0.002f, 0.012f);
    gf2[i] = frand(0.006f, 0.022f);
    gp1[i] = frand(0, 6.283f);
    gp2[i] = frand(0, 6.283f);
  }
}

void loop() {
  float t = millis() / 1000.0f;

  // 1) Update the coarse field (336 points, cheap).
  for (int i = 0; i < GW * GH; i++) {
    float v = 0.5f + 0.30f * sinf(t * gf1[i] * 6.283f + gp1[i])
                   + 0.20f * sinf(t * gf2[i] * 6.283f + gp2[i]);
    g[i] = (uint8_t)(v * 255.0f);
  }

  // 2) Soft threshold LUT: light where field > th; wide smooth penumbra.
  //    Threshold itself gusts slowly = clouds/wind opening & closing gaps.
  float th = 0.58f + 0.06f * sinf(t * 0.013f) + 0.03f * sinf(t * 0.031f + 2.1f);
  float edge = 0.16f; // penumbra width
  for (int i = 0; i < 256; i++) {
    float x = (i / 255.0f - th) / edge;
    x = (x < 0) ? 0 : ((x > 1) ? 1 : x);
    x = x * x * (3.0f - 2.0f * x);          // smoothstep
    lut[i] = (uint8_t)(powf(x, 1.25f) * 235.0f); // cap under palette white
  }

  // 3) Bilinear-upsample field → pixels, through the LUT.
  uint8_t *buf = display.getBuffer();
  for (int y = 0; y < H; y++) {
    int gy = y / CELL, fy = y % CELL;
    const uint8_t *r0 = g + gy * GW;
    const uint8_t *r1 = g + (gy + 1) * GW;
    uint8_t *row = buf + y * W;
    for (int gx = 0; gx < GW - 1; gx++) {
      int a = r0[gx] * (CELL - fy) + r1[gx] * fy;         // 0..255*16
      int b = r0[gx + 1] * (CELL - fy) + r1[gx + 1] * fy;
      uint8_t *p = row + gx * CELL;
      for (int fx = 0; fx < CELL; fx++) {
        int val = (a * (CELL - fx) + b * fx) >> 8;        // 0..255
        p[fx] = lut[val];
      }
    }
  }
  display.swap();
}

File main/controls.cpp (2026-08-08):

// controls.cpp — see controls.h for the polling-vs-interrupt rationale.
#include "controls.h"
#include "config.h"

// Full quadrature state table, index = (prevAB << 2) | currAB.
// +1/-1 = valid quarter-step, 0 = no move, 99 = impossible jump (both
// lines changed = a missed sample; harmless noise-reject here, since the
// ISR runs per edge). Same table as the shadow_puppet encoder-test.
const int8_t RotaryEncoder::QDEC[16] = {
   0, -1, +1, 99,
  +1,  0, 99, -1,
  -1, 99,  0, +1,
  99, +1, -1,  0
};

RotaryEncoder* RotaryEncoder::self = nullptr;

void RotaryEncoder::begin(uint8_t pinA, uint8_t pinB) {
  pinA_ = pinA; pinB_ = pinB;
  pinMode(pinA_, INPUT_PULLUP);  // KY-040 has its own pull-ups; harmless
  pinMode(pinB_, INPUT_PULLUP);
  prevAB_ = (digitalRead(pinA_) << 1) | digitalRead(pinB_);
  self = this;
  attachInterrupt(digitalPinToInterrupt(pinA_), isrTrampoline, CHANGE);
  attachInterrupt(digitalPinToInterrupt(pinB_), isrTrampoline, CHANGE);
}

void RotaryEncoder::isrTrampoline() { if (self) self->handleEdge(); }

void RotaryEncoder::handleEdge() {
  uint8_t ab = (digitalRead(pinA_) << 1) | digitalRead(pinB_);
  if (ab == prevAB_) return;
  int8_t d = QDEC[(prevAB_ << 2) | ab];
  if (d != 99) quarters_ += d;   // ignore impossible jumps
  prevAB_ = ab;
}

int RotaryEncoder::consumeDetents() {
  noInterrupts();
  int32_t q = quarters_;
  interrupts();
  int32_t det = q / 4;           // 4 quarter-steps per detent (KY-040)
  int out = (int)(det - taken_);
  taken_ = det;
  return out;
}

void ClickButton::begin(uint8_t pin) {
  pin_ = pin;
  pinMode(pin_, INPUT_PULLUP);
}

ClickButton::Event ClickButton::poll(uint32_t now) {
  bool down = (digitalRead(pin_) == LOW);
  Event ev = NONE;
  if (down && !wasDown_) {                   // press edge
    pressedAt_ = now;
  } else if (!down && wasDown_) {            // release edge
    uint32_t held = now - pressedAt_;
    if (held >= LONGPRESS_MS)      ev = LONG_PRESS;
    else if (held >= DEBOUNCE_MS)  ev = CLICK;
    // < DEBOUNCE_MS: contact bounce, swallow it.
  }
  wasDown_ = down;
  return ev;
}

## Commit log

2026-08-08 Add two diffable variants: komorebi_sized (3 size classes + ellipticity), komorebi_noise (morphing noise-field style); stronger boot entropy
    [komorebi_noise.ino]
2026-08-08 komorebi_sized: edge vignette (dissolve projection frame) + slow shape-breathing morph borrowed from noise style
2026-08-08 Promote sized variant to main/; add README with pipeline + mood-button diagrams (assets/)
2026-08-08 Surprise button on GP6/pin9: debounced press = fade out, re-seed, re-deal, fade in; README + diagram updated
2026-08-08 Spike tests: density limits (8-28 good, 36 saturates) + EEPROM/PicoDVI incompatibility proven (flash write kills core1 DVI)
    [density_spike.ino, eeprom_dvi_spike.ino]
2026-08-08 Refactor main/ into modules (config/controls/render/engine/params) + encoder controls: click-cycled warmth/breeze/density with visual announcements. Compile-verified, NOT flashed (HW being soldered)
2026-08-08 Swap surprise button (GP7/pin10) and encoder A (GP6/pin9); sync comments in config, main.ino header, README
    [config.h, main.ino]
2026-08-08 Fix palette strobe: DVIGFX8 has one palette per buffer — write palette changes on two consecutive frames
2026-08-08 config: document encoder wiring as A=DT, B=CLK; note swap only inverts direction (software fix if needed)
    [config.h]
2026-09-13 Pico 2 W: WiFi spikes + boot-time portal module (not yet wired in)
    - tests/wifi_dvi_spike: scan, softAP, WebServer with PicoDVI live at
    252 MHz sysclk. PASS (CYW43 fixed PIO clock div is fine).
    - tests/core1reset_flash_spike: EEPROM write after display.begin() with
    core1 stopped (multicore_reset_core1 in v1, PSM hold in v2). Both
    freeze the board inside EEPROM.commit(). Rule: no flash writes after
    DVI starts, ever.
    - main/wifi_portal.{h,cpp}: pre-DVI boot sequence (stored creds -> connect,
    else captive portal on AP with scanned SSID list, EEPROM save, reboot);
    long-press reconfigure via watchdog scratch flag. Not yet called from
    main.ino, config.h constants pending.
    [core1reset_flash_spike.ino, wifi_dvi_spike.ino, wifi_portal.cpp]
2026-09-13 WiFi portal wired into main: boot-time connect or captive portal
    - config.h: AP name/password, connect (15 s) and portal (3 min) timeouts.
    - main.ino: wifi.boot() before display.begin() (flash writes only pre-DVI);
    encoder long-press = forget network + reboot into portal.
    - wifi_portal: show-password toggle, Rescan button (drops AP, scans in
    STA, restores AP), Serial boot log with 2 s host wait.
    Verified on the wall board: portal on first boot, credentials saved,
    reboot, joined LAN (ip via DHCP), art running.
    [config.h, main.ino, wifi_portal.cpp]
2026-09-13 Docs: Pico 2 W + Pico DVI Sock, WiFi portal section, flash rule, spike index
2026-09-13 Encoder SW moved to GP5 (physical pin 7) on the Pico 2 W build; docs updated
2026-09-14 Sky layer stage 1: pure core (JSON scan, sun position, model, decay) + host tests
    main/sky_core.{h,cpp}: no Arduino deps, compiled on Mac and Pico.
    tests/sky_host: 54 checks against real Open-Meteo and ip-api responses
    captured 2026-09-14, truncation/reorder/missing/garbage inputs, sun
    position vs Open-Meteo sunrise/sunset and solstice noons (all within
    0.15 deg), model for clear/overcast/golden/night/storm, 6 h decay.
    Not yet called from the sketch.
    [sky_core.h]
2026-09-14 Sky layer stage 2 (partial): SkyClient fetch layer, on-board spike, flash helper
    - main/sky.{h,cpp}: SkyClient (ip-api location, NTP, Open-Meteo weather),
    plain HTTP/1.0, boot sync pre-DVI, per-frame tick, hourly refresh,
    5-min retry, WiFi watchdog, staleness decay, serial status.
    - tests/sky_spike: real code via symlinks, DVI live, frame-stall meter,
    serial failure injection. Verified: boot sync 1.5 s, correct model,
    17 ms max frame gap.
    - FOUND: DVI's 252 MHz sysclk runs the CYW43 PIO SPI over spec (63 MHz
    vs 50 max) -> lossy link, 2-5 s connects. FIX: cyw43_set_pio_clkdiv
    _int_frac8(3,0) before first WiFi call -> 30 ms connects with DVI live.
    Not yet applied to main/.
    - test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
    [sky.cpp, sky_core.h, sky_spike.ino]
2026-09-14 Sky layer: non-blocking reconnect, reassociate after 2 failed fetches, divisor fix in the layer, stage 3 wiring in main (log only)
    - sky.cpp: WiFi.beginNoBlock for reconnects (no more 5 s freezes while
    the link is down); 2 consecutive failed fetches while 'connected' ->
    disconnect + fresh association (fresh lease/DNS); HTTP status line
    logged on failure; setRefreshMs reschedules.
    - SkyClient::prepareRadioForDvi(): CYW43 PIO SPI divisor 3, called first
    in setup(). Applied in main.ino.
    - main.ino: sky bootSync after wifi.boot() (pre-DVI), tick() per frame,
    status line every 10 min. Engine untouched. NOT flashed yet: soak 2
    running on the spike first.
    - wifi_portal: ssid()/pass() ac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
    [main.ino, sky.cpp, sky_spike.ino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]
2026-09-14 Sky layer: keepalive + noLowPowerMode; main runs the sky layer log-only
    Diagnosis (spike, 2026-09-14 12:30-13:10, with Mac-side reference log):
    - Your network was fine throughout (router + API 100% from the Mac).
    - With DVI live the STA link goes deaf after minutes of idle: board
    unpingable, DNS and TCP time out, status still 'connected'.
    - Not the clock: no-DVI at 252 MHz is perfect (fetch 17 ms, all pings).
    Not power save: noLowPowerMode alone changed nothing. DVI activity
    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
2026-09-14 Docs: 'Two hard-won facts about WiFi and video on one Pico', sky status, spike index
2026-09-14 Stage 4: the sky drives the light
    - sky_core: mapOffsets (vector -> signed offsets, complement/mirror =
    sign flip, influence scale). Host tests: 60 checks.
    - engine: exposure gain in the palette (black stays black); sky offsets
    slewed toward targets over SKY_SLEW_S; effective warmth/breeze/density
    = encoder + sky, clamped; palette rebuilt on effective changes.
    - config: SKY_RANGE_* (25/25/5 dapples/30%), SKY_INFLUENCE 1.0 (tuning),
    SKY_SLEW_S 180, DOUBLE_CLICK_MS 350, LOG_VERBOSE switch.
    - main: double-click on the surprise button flips complement/mirror
    (first click still breathes), targets re-pushed every minute and after
    each fetch, snapshot dump at boot / fetch / mode flip.
    -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
    [config.h, main.ino, sky.cpp]
2026-09-14 Contrast: 4th encoder parameter + sky crispness dimension
    - params: contrast 0..100 (default 50); click cycle warmth -> breeze ->
    density -> contrast.
    - sky model: crisp (0 flat overcast/rain .. 1 clear sun) from cloud and
    precipitation; cloud now also cools the warmth cue (up to 40%).
    Host tests: 66 checks.
    - engine: contrast drives pool size (1.25x .. 0.75x), pool brightness
    (0.8 .. 1.2) and palette gamma (x0.8 .. x1.2); announcement = all
    pools briefly tighten and brighten. Sky contrast offset slewed like
    the others (SKY_RANGE_CONTRAST 25).
    - logs/dump include crisp and contrast.
    [config.h, main.ino, sky.cpp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]
2026-09-15 Watchdog (8 s) + black-box stage recorder in watchdog scratch[3]
    The board died after ~1 h on the wall and needed a power cycle. Now:
    a loop stall > 8 s reboots it, and the boot log names the last stage
    (fetch connect/send/read/parse, reassociate, keepalive, dump, render,
    inputs) so the culprit is identifiable from serial. Note: Pico core
    updated 6.0.0 -> 6.1.0 on the Mac at 13:02 on 14 Sept; all wall builds
    since then are on 6.1.0.
    [main.ino, sky.cpp]
2026-09-15 Bisect switch SKY_LIVE_NET (0 = boot fetch only, radio off), stage 14 = swap, DVI late-scanline counter in the minute line
    Recorder result 15 Sept: two watchdog reboots (15:02, 15:03), both
    last stage 12 = render+swap, both within a minute of a weather fetch.
    swap() spins until the video core clears a flag, so core1 had stopped.
    Suspect: WiFi SPI DMA traffic disturbing the DVI DMA chain (core1's IRQ
    busy-waits on its channel state). Overnight run with SKY_LIVE_NET 0
    decides it.
    [config.h, main.ino]
2026-09-16 The sigh: fetch pre-DVI only, refresh by a short reboot every 3 h
    Bisect 15/16 Sept: radio off after boot = 16.5 h, 998 minute lines,
    no stall, DVI late 0. WiFi traffic under DVI was killing the video
    core. SKY_LIVE_NET stays 0.
    - engine: SighOut/Dark fade states; every boot breathes in; snapSkyToTargets.
    - main: every SKY_SIGH_MINUTES the light breathes out, dials + mode are
    packed into watchdog scratch[1..2], rp2040.reboot(); boot restores
    them, fetches, snaps the sky offsets, breathes in. Tested 4/4 cycles
    at 3 min with the user watching: monitor re-syncs, dials survive.
    - sky: staleness decays only the weather part; sun and season stay
    live from the clock (they were wrongly fadin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
    [config.h, main.ino, sky.cpp]
2026-09-17 Docu updated
    [BASE.step, BTN_EXTENDER.step, CAP.step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]
